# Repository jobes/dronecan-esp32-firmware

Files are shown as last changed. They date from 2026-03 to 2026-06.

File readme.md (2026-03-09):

# InSkyCore DroneCAN Firmware Platform

Low-cost ESP32-based avionics devices for experimental aviation.

This repository is a multi-firmware platform for building DroneCAN nodes and sensors for:

- experimental and ultralight airplanes
- powered hang gliders
- custom cockpit projects

The practical goal is simple: publish important flight and engine data over DroneCAN so the pilot can see everything critical on a tablet in the cockpit.

## Vision

This project focuses on:

- affordable hardware built around ESP32
- reusable DroneCAN software components
- multiple device firmwares in one repository
- fast iteration for real-world flying needs

## Safety Notice

This project is intended for experimental use.

It is not a certified avionics system and must not be treated as the sole source of flight-critical information. Always keep independent, appropriate backup instrumentation.

## Repository Layout

```text
firmware/
	components/                  # Shared ESP-IDF components used by all firmwares
		dronecan_mini/             # DroneCAN communication, node state, params, FW update
		bmp3_sensor_api/           # BMP3/BMP390 sensor integration component
		libcanard/                 # ESP-IDF wrapper/component for libcanard

	firmwares/
		<firmware-name>/           # Individual firmware projects (each has its own README)

	submodules/
		libcanard/                 # Upstream libcanard submodule
		bmp3_sensor_api/           # Upstream BMP3 sensor API submodule
```

## Firmware-Specific Documentation

Each firmware under `firmwares/` has (or should have) its own `readme.md` with:

- hardware details and pinout
- published DroneCAN messages/services
- target MCU and board notes
- exact build/flash commands
- calibration and test notes

## Requirements

- Linux development environment
- ESP-IDF installed (compatible with your project setup)
- USB access to target board
- CAN transceiver and proper wiring for DroneCAN bus

## Quick Start

Clone with submodules:

```bash
git clone --recurse-submodules <REPO_URL>
cd firmware
```

If already cloned, update submodules:

```bash
git submodule update --init --recursive
```

Load ESP-IDF environment:

```bash
. /opt/esp-idf/export.sh
```

Build and flash a selected firmware:

```bash
cd firmwares/<firmware-name>
# Follow target selection and configuration in that firmware's readme.md
idf.py -p /dev/ttyACM1 build flash monitor
```

## How To Add a New Device Firmware

1. Create a new folder under `firmwares/`.
2. Add a standard ESP-IDF project (`CMakeLists.txt`, `main/`, config files).
3. Reuse shared logic from `../../components` (especially `dronecan_mini`).
4. Define per-device settings in `main/project_config.h`.
5. Add sensor/application code in `main/` and publish required DroneCAN topics.
6. Build, flash, and validate on a real CAN bus.

## Design Principles

- Keep common DroneCAN logic in shared components.
- Keep firmware-specific hardware details in each firmware folder.
- Prefer explicit parameters for in-field calibration.
- Optimize for robustness and predictable behavior over features.

## Roadmap Ideas

- additional air-data and environmental sensors
- engine monitoring nodes (EGT/CHT, RPM, pressures)
- electrical system telemetry (voltage/current/battery)
- GPS/attitude helper nodes for glass-cockpit integration
- standardized tablet-friendly data profiles

## Contribution

Contributions and practical flight-test feedback are welcome.

Recommended contribution style:

- keep commits focused and small
- document pinout/protocol assumptions
- include test notes (bench or flight context)

## License

Add the project license information here (for example MIT, BSD, or GPL) once finalized.

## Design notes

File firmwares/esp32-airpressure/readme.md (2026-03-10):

# ESP32 Air Pressure Firmware

Firmware for an ESP32-C3 based DroneCAN air data node using a BMP390 pressure sensor over SPI.

## What This Firmware Does

- Initializes the BMP390 sensor over SPI.
- Joins DroneCAN network over TWAI/CAN.
- Uses DroneCAN dynamic node ID allocation at startup.
- Publishes:
  - `uavcan.equipment.air_data.StaticPressure` (type ID `1028`)
  - `uavcan.equipment.air_data.StaticTemperature` (type ID `1029`)
- Publishes heartbeat (`uavcan.protocol.NodeStatus`) approximately every `950 ms`.
- Exposes runtime parameters for pressure and temperature offsets.

## Hardware Configuration

Defined in `main/project_config.h`.

### CAN (TWAI)

- `CAN_TX_PIN`: `GPIO21`
- `CAN_RX_PIN`: `GPIO20`
- Bitrate: `1 Mbit/s` (`TWAI_TIMING_CONFIG_1MBITS`)

Note: ESP32-C3 requires an external CAN transceiver between MCU TWAI pins and CAN bus.

### BMP390 (SPI)

- `BMP_SCLK`: `GPIO4`
- `BMP_MISO`: `GPIO5`
- `BMP_MOSI`: `GPIO6`
- `BMP_CS`: `GPIO7`
- SPI clock: `1 MHz`

## DroneCAN Node Behavior

- Node starts in `MODE_INITIALIZATION`.
- During startup it requests a dynamic node ID using its unique ID.
- After successful initialization, application switches to `MODE_OPERATIONAL`.
- Main loop period is `100 ms`.
- If sensor read or publish fails, node health is degraded (`WARNING/ERROR/CRITICAL` depending on failure).

## Runtime Parameters

The node registers two float parameters (available over DroneCAN param services):

- `pressure_offset`
  - Range: `-100.0 .. 100.0`
  - Default: `0.0`
  - Applied to published pressure in pascals.
- `temp_offset`
  - Range: `-10.0 .. 10.0`
  - Default: `0.0`
  - Applied to published temperature in degrees Celsius.

Parameters are backed by NVS and can be saved/erased through standard DroneCAN parameter opcodes.

## Build and Flash

From repository root:

```bash
. /opt/esp-idf/export.sh
cd firmwares/esp32-airpressure
# idf.py set-target esp32c3 already set
idf.py -p /dev/ttyACM1 build flash monitor
```

If target is already set, you can skip `set-target`.

## Useful Commands

```bash
# Build only
idf.py build

# Flash only
idf.py -p /dev/ttyACM1 flash

# Monitor only
idf.py -p /dev/ttyACM1 monitor
```

## Project Structure Notes

- Shared components are taken from `../../components`.
- Shared submodules are located in `../../submodules`.
- Partition table is defined in `partitions.csv` (OTA slots + SPIFFS storage).

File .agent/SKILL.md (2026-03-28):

---
name: DroneCAN Firmware Developer
description: Expert in DroneCAN firmware development for ESP32 using ESP-IDF.
---

# DroneCAN ESP32 Firmware Developer Skill

This skill provides expert guidance and automated workflows for developing DroneCAN-based firmware on ESP32 microcontrollers using the ESP-IDF framework.

## Project Structure

- `components/`: Shared ESP-IDF components.
  - `dronecan_mini/`: High-level DroneCAN abstraction (DNA, Parameters, Firmware Update).
  - `libcanard/`: ESP-IDF wrapper for the libcanard library.
- `firmwares/`: Individual firmware projects for different devices.
  - `esp32-airpressure/`: Air pressure sensor node.
  - `esp32-gateway/`: General purpose DroneCAN gateway.
- `submodules/`: External libraries as Git submodules.

## Core Technologies

- **ESP-IDF**: The official development framework for ESP32.
- **DroneCAN**: A lightweight, robust CAN bus protocol for UAVs and robotics.
- **Libcanard**: The underlying DroneCAN implementation in C.

## Multi-Firmware Scalability Strategy

This project is designed to scale to dozens of unique firmware targets. Follow these guidelines to keep the project clean:

### 1. Unified Shared Components
- All logic that can be reused (DroneCAN init, DNA, Heartbeat, Common Messages) must live in `components/dronecan_mini/`.
- Sensor-specific drivers (e.g., BMP380, INA226) should be added as separate components in `components/`

### 2. Standardized Firmware Project Layout
Each firmware in `firmwares/` should follow this template:
- `main/main.c`: The entry point and firmware-specific logic.
- `main/project_config.h`: Key hardware settings (pins, node names, timings).
- `partitions.csv`: Custom partition layout.
- `CMakeLists.txt`: Renames the project and links shared components.
- `readme.md`: Documents HW pinout, specific DroneCAN IDs used, and build notes.

### 3. Naming Conventions
- Firmware folders: `esp32-<functionality>` (e.g., `esp32-egt-sensor`, `esp32-fuel-flow`).
- Node names: `com.inskycore.<firmware-name>` (defined in `project_config.h`).

## Development Workflow

### 1. Build & Flash
Always build and flash from the specific firmware directory under `firmwares/`.

```bash
cd firmwares/<firmware-name>
idf.py build flash monitor
```

### 2. DroneCAN Message Handling
- Shared message definitions are in `components/dronecan_mini/messages/`.
- Receiver logic is in `dronecan_receiver.c`.
- Transmitter logic is typically in `main.c` or a dedicated task.

### 3. Parameters & Configuration
- Per-project configuration is in `main/project_config.h`.
- Custom parameters should be registered in the `dronecan_mini` parameter system.

## Best Practices

1. **Reusability**: Keep protocol-specific and sensor-abstracted logic in `components/`.
2. **Firmware Decoupling**: Keep board-specific pinouts and hardware initialization in the `firmwares/` project's `main/` directory.
3. **Serial Monitoring**: Use `idf.py monitor` for real-time logs.
4. **Git Submodules**: Ensure submodules are updated using `git submodule update --init --recursive`.

## Useful Commands

- `idf.py -p <PORT> build flash monitor`: Complete cycle for a specific firmware.
- `idf.py menuconfig`: Configure firmware settings (WiFi, CAN pins, etc.).
- `idf.py fullclean`: If you encounter weird build issues.

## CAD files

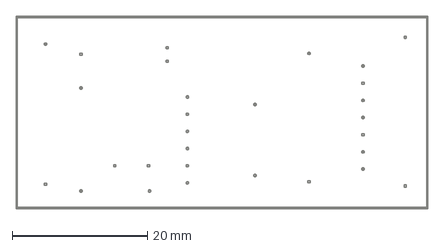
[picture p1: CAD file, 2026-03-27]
firmwares/esp32-airpressure/pcb-supermini-c3-bmp390/pcb-supermini-c3-bmp390-Edge_Cuts.dxf
61.0 x 28.5 mm

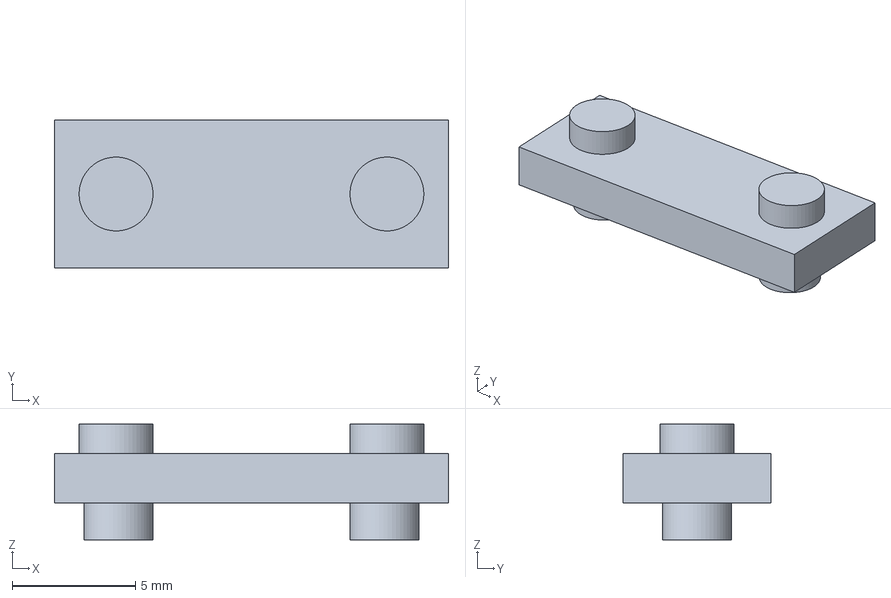
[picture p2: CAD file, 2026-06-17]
firmwares/esp32-airpressure/under-can-holder.FCStd
16.0 x 6.00 x 4.70 mm

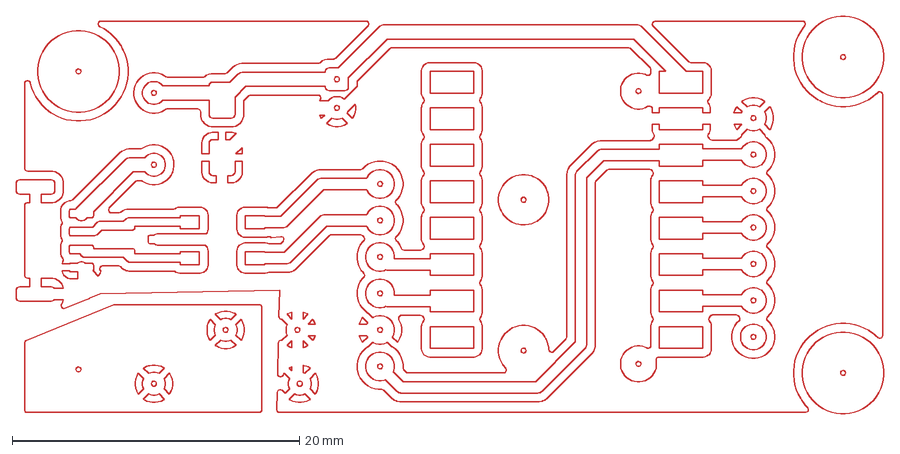
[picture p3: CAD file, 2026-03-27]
firmwares/esp32-airpressure/pcb-supermini-c3-bmp390/pcb-supermini-c3-bmp390-F_Cu.dxf
60.4 x 27.7 mm

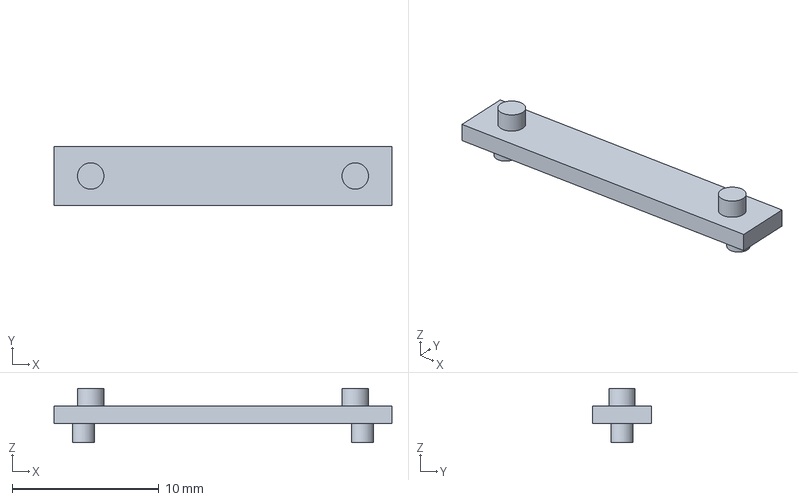
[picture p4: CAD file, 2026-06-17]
firmwares/esp32-airpressure/under-bmp390-holder.FCStd
23.0 x 4.00 x 3.70 mm

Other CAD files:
firmwares/esp32-airpressure/pcb-supermini-c3-bmp390/pcb-supermini-c3-bmp390-F_Mask.dxf

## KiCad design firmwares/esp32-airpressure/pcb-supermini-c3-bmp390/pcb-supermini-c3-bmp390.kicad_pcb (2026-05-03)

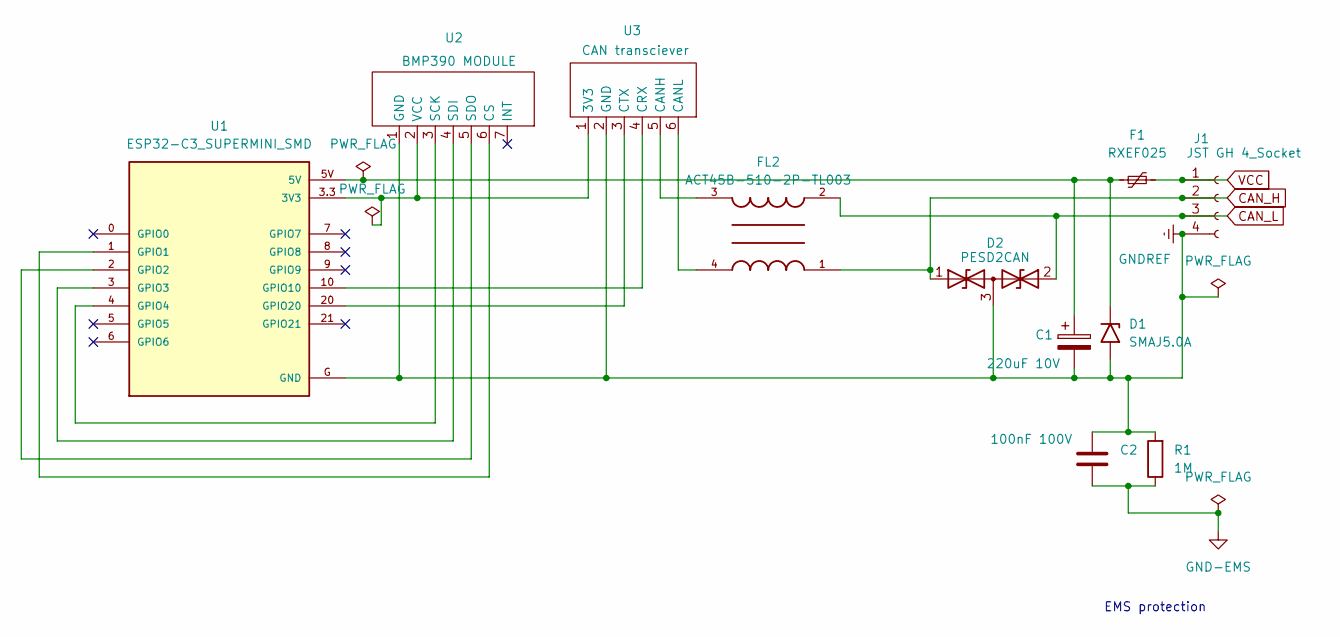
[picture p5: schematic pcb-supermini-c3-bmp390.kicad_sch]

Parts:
C1: 220uF 10V; CP_Radial_D5.0mm_P2.00mm
C2: 100nF 100V; C_Rect_L7.2mm_W3.0mm_P5.00mm_FKS2_FKP2_MKS2_MKP2
D1: SMAJ5.0A; D_SMA
D2: PESD2CAN; SOT-23-3
F1: RXEF025; C_Disc_D4.7mm_W2.5mm_P5.00mm
FL2: ACT45B-510-2P-TL003; FIL_ACT45B-510-2P-TL003; PARTREV 20200405
J1: JST GH 4_Socket; JST_GH_SM04B-GHS-TB_1x04-1MP_P1.25mm_Horizontal
R1: 1M; R_Axial_DIN0207_L6.3mm_D2.5mm_P10.16mm_Horizontal
U1: ESP32-C3_SUPERMINI_SMD; MODULE_ESP32-C3_SUPERMINI
U2: BMP390 MODULE; BMP390_Module
U3: CAN transciever; CAN_Module

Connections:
CAN_H: D2.1 (A1), FL2.1, J1.2
CAN_L: D2.2 (A2), FL2.2, J1.3
GND-EMS: C2.2, R1.1
GNDREF: C1.2, C2.1, D1.2 (A2), D2.3 (common), J1.4, R1.2, U1.G (GND), U2.1 (GND), U3.2 (GND)
unnamed: C1.1, D1.1 (A1), F1.1, U1.5V
unnamed: U1.3.3 (3V3), U2.2 (VCC), U3.1 (3V3)
unnamed: U1.1 (GPIO1), U2.6 (CS)
unnamed: U1.2 (GPIO2), U2.5 (SDO)
unnamed: U1.3 (GPIO3), U2.4 (SDI)
unnamed: U1.4 (GPIO4), U2.3 (SCK)
unnamed: U1.10 (GPIO10), U3.4 (CRX)
unnamed: U1.20 (GPIO20), U3.3 (CTX)
unnamed: FL2.3, U3.5 (CANH)
unnamed: FL2.4, U3.6 (CANL)
VCC: F1.2, J1.1

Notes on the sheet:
EMS protection

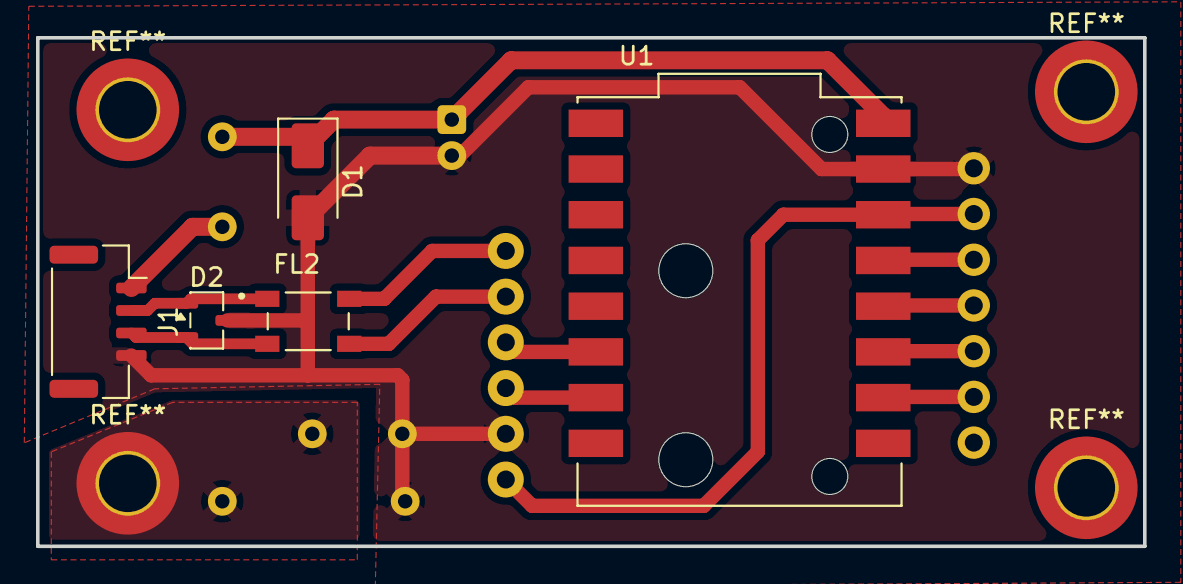
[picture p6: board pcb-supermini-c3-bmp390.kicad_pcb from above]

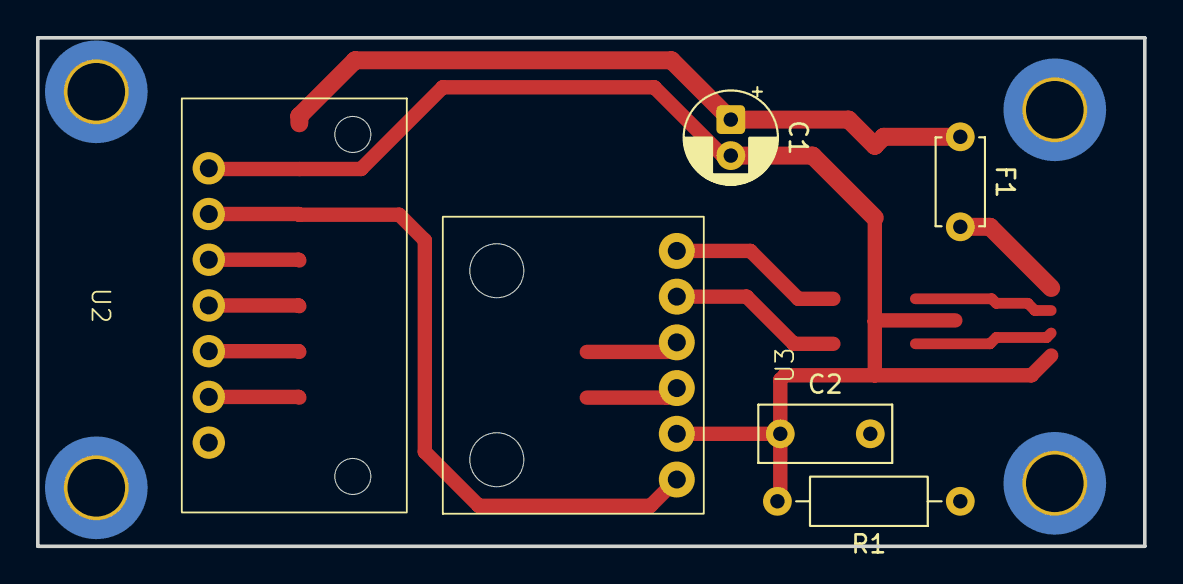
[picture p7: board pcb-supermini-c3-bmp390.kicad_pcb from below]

Board: 2 copper layers, 61.5 x 28.2 mm, 11 parts (6 on the bottom side), 15 nets.

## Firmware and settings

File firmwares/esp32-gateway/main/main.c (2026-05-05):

#include "dronecan_mini/dronecan_tasks.h"
#include "dronecan_dna_server.h"
#include "esp_log.h"

#include "cannelloni_bridge.h"
#include "dronecan_mini/dronecan_node_state.h"
#include "dronecan_mini/dronecan_value_params.h"
#include "dronecan_node_monitor.h"
#include "dronecan_mini/messages/uavcan.equipment.air_data.StaticPressure-1028.h"
#include "dronecan_mini/messages/uavcan.equipment.air_data.StaticTemperature-1029.h"
#include "wifi_manager.h"

static const char *TAG = "APP";

static void main_task(void *arg)
{
  ESP_LOGI(TAG, "Application task started");

  if (*get_node_mode() == MODE_INITIALIZATION)
  {
    set_node_mode(MODE_OPERATIONAL);
  }

  while (1)
  {
    if (*get_node_mode() != MODE_OPERATIONAL)
    {
      ESP_LOGW(
          TAG,
          "Node is not in operational mode, skipping sensor read and publish");
      vTaskDelay(pdMS_TO_TICKS(1000));
      continue;
    }
    dronecan_node_monitor_tick();
    vTaskDelay(pdMS_TO_TICKS(100));
  }
}

void app_main(void)
{
  union DeviceParameter device_parameters[] = {
      {.String = {DEVICE_PARAM_TYPE_STRING, "HOSTNAME", "airplane_gateway"}},
      {.String = {DEVICE_PARAM_TYPE_STRING, "AP_SSID", "airplane_gateway"}},
      {.String = {DEVICE_PARAM_TYPE_STRING, "AP_PASSWORD", "airplane123456"}},
      {.String = {DEVICE_PARAM_TYPE_STRING, "STA_SSID", ""}},
      {.String = {DEVICE_PARAM_TYPE_STRING, "STA_PASSWORD", ""}},
  };

  set_device_parameters(device_parameters, ARRAY_SIZE(device_parameters));
  wifi_init_manager();
  cannelloni_bridge_init();
  dronecan_set_rx_frame_listener(cannelloni_bridge_push_frame);
  dronecan_set_tx_frame_listener(cannelloni_bridge_push_frame);
  init_tasks(main_task, 1, 1); // Core 1 for CAN/DroneCAN tasks
  dronecan_dna_server_init();
}

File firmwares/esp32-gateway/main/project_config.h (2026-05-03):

#ifndef PROJECT_CONFIG_H
#define PROJECT_CONFIG_H

// stringify helper
#define _STR(x) #x
#define STR(x) _STR(x)

// node info
#define DEVICE_NAME "com.inskycore.dronecan_node.gateway"
#define DEVICE_NAME_LEN (sizeof(DEVICE_NAME) - 1)
#define DEVICE_INSTANCE_NAME "avionics-dronecan"
#define DEVICE_INSTANCE_NAME_LEN (sizeof(DEVICE_INSTANCE_NAME) - 1)

#define MINOR_SW_VERSION 1
#define MAJOR_SW_VERSION 0

#define MINOR_HW_VERSION 1
#define MAJOR_HW_VERSION 0

// dronecan
#define CAN_TX_PIN GPIO_NUM_17
#define CAN_RX_PIN GPIO_NUM_18
#define CAN_SPEED TWAI_TIMING_CONFIG_1MBITS
#define CAN_CONFIG TWAI_FILTER_CONFIG_ACCEPT_ALL
#define CAN_MODE TWAI_MODE_NORMAL
#define CAN_READ_TIMEOUT_MS 10
#define DRONECAN_MEM_POOL_SIZE 4096
#define DRONECAN_HEARTBEAT_INTERVAL_MS 950 // 1 second interval with some margin

// cannelloni
#define CANNELLONI_UDP_PORT 20000
#define CANNELLONI_MAX_PEERS 5
#define CANNELLONI_PEER_TIMEOUT_MS 3000
#define CANNELLONI_TX_INTERVAL_MS 10

#endif

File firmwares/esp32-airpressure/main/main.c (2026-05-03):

#include "dronecan_mini/dronecan_tasks.h"
#include "esp_log.h"

#include "bmp390.h"
#include "dronecan_mini/dronecan_value_params.h"
#include "dronecan_mini/dronecan_node_state.h"
#include "dronecan_mini/messages/uavcan.equipment.air_data.StaticPressure-1028.h"
#include "dronecan_mini/messages/uavcan.equipment.air_data.StaticTemperature-1029.h"

static const char *TAG = "APP";

static void main_task(void *arg)
{
    ESP_LOGI(TAG, "Application task started");
    if (bmp390_spi_init() != ESP_OK)
    {
        set_node_health(HEALTH_CRITICAL);
        vTaskDelete(NULL);
    }

    if (*get_node_mode() == MODE_INITIALIZATION)
    {
        set_node_mode(MODE_OPERATIONAL);
    }

    while (1)
    {
        if (*get_node_mode() != MODE_OPERATIONAL)
        {
            ESP_LOGW(TAG, "Node is not in operational mode, skipping sensor read and publish");
            vTaskDelay(pdMS_TO_TICKS(1000));
            continue;
        }
        struct bmp3_data data;
        if (bmp390_get_data(&data) == BMP3_OK)
        {
            float pressure_variance_pa2 = 100.0f; // 0.8 meters variance
            float temperature_variance_c2 = 1.0f; // 1 degrees Celsius variance

            bool pressure_publish_ok = publish_1028_staticPressure((float)data.pressure + get_device_parameters()[0].Float.value, pressure_variance_pa2);
            bool temperature_publish_ok = publish_1029_staticTemperatureCelsius((float)data.temperature + get_device_parameters()[1].Float.value, temperature_variance_c2);

            if (pressure_publish_ok && temperature_publish_ok)
            {
                set_node_health(HEALTH_OK);
            }
            else
            {
                if (temperature_publish_ok)
                {
                    ESP_LOGE(TAG, "Failed to publish static pressure");
                    set_node_health(HEALTH_CRITICAL);
                }
                else
                {
                    ESP_LOGE(TAG, "Failed to publish temperature");
                    set_node_health(HEALTH_ERROR);
                }
            }
        }
        else
        {
            ESP_LOGE(TAG, "Failed to read data from BMP390 sensor");
            set_node_health(HEALTH_CRITICAL);
        }
        vTaskDelay(pdMS_TO_TICKS(100));
    }
}

void param_changed(uint16_t index)
{
    ESP_LOGI(TAG, "Parameter index %d changed", index);
}

void app_main(void)
{
    union DeviceParameter device_parameters[] = {
        {.Float = {DEVICE_PARAM_TYPE_FLOAT, "pressure_offset", -100.0, 100.0, 0.0}},
        {.Float = {DEVICE_PARAM_TYPE_FLOAT, "temp_offset", -10.0, 10.0, 0.0}},
    };

    set_param_changed_callback(param_changed);
    set_device_parameters(device_parameters, ARRAY_SIZE(device_parameters));
    init_tasks(main_task, 0, tskNO_AFFINITY);
}

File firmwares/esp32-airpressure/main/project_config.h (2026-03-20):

#ifndef PROJECT_CONFIG_H
#define PROJECT_CONFIG_H

// node info
#define DEVICE_NAME "com.inskycore.dronecan_node.pressure_sensor"
#define DEVICE_NAME_LEN (sizeof(DEVICE_NAME) - 1)
#define MINOR_SW_VERSION 1
#define MAJOR_SW_VERSION 0

#define MINOR_HW_VERSION 1
#define MAJOR_HW_VERSION 0

// dronecan
#define CAN_TX_PIN GPIO_NUM_20
#define CAN_RX_PIN GPIO_NUM_10
#define CAN_SPEED TWAI_TIMING_CONFIG_1MBITS
#define CAN_CONFIG TWAI_FILTER_CONFIG_ACCEPT_ALL
#define CAN_MODE TWAI_MODE_NORMAL
#define CAN_READ_TIMEOUT_MS 10
#define DRONECAN_MEM_POOL_SIZE 4096
#define DRONECAN_HEARTBEAT_INTERVAL_MS 950 // 1 second interval with some margin

// BMP390
#define BMP_CS GPIO_NUM_1
#define BMP_MISO GPIO_NUM_2
#define BMP_MOSI GPIO_NUM_3
#define BMP_SCLK GPIO_NUM_4
#define SPI_SPEED_HZ 1000000

#endif

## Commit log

2026-02-20 add BMP390 sensor integration and update project configuration
2026-02-20 add static pressure publishing to DroneCAN and update broadcast function
2026-02-20 move pressure message to own file
2026-02-20 add StaticTemperature message handling and integrate temperature publishing
2026-02-22 device parameters load from nvm, but can be changed via can
2026-02-22 Implement parameter change notification and refactor device parameter handling
2026-02-25 firmware update over CAN
    [partitions.csv]
2026-03-09 make library style so we can have more firmware
    [partitions.csv]
2026-03-10 update readme to clarify that target for esp32c3 is already set
2026-03-19 Add symbol library and components for BMP390 and CAN transceiver
    - Created a new symbol library file for the ESP32-C3 Supermini project.
    - Added symbols for BMP390 module and CAN transceiver with their respective properties and pin configurations.
    - Included necessary metadata for the symbol library to ensure compatibility with KiCad.
    [pcb-supermini-c3-bmp390.kicad_pcb, pcb-supermini-c3-bmp390.kicad_sch]
2026-03-20 refactor: update PCB to be on 2 layers
    [pcb-supermini-c3-bmp390.kicad_pcb, pcb-supermini-c3-bmp390.kicad_sch]
2026-03-20 chore: Update libcanard core, drivers, tests, examples, C++ wrappers, and build configurations.
2026-03-27 feat: Add new ESP32 air pressure sensor PCB design
    [pcb-supermini-c3-bmp390-Edge_Cuts.dxf, pcb-supermini-c3-bmp390-F_Cu.dxf, pcb-supermini-c3-bmp390-F_Mask.dxf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]
2026-03-28 esp32-gateway empty basic empty firmware
    [partitions.csv]
2026-03-28 feat: Implement Wi-Fi manager and device parameter retrieval functions
    [partitions.csv]
2026-03-28 feat: Add HTTP server and mDNS service for device discovery
2026-03-28 feat: Advertise Cannelloni service for CAN bus tunneling in mDNS
2026-05-03 Refactor ESP32 Gateway Firmware
    - Updated main.c to include cannelloni_bridge and improved task management.
    - Modified project_config.h to change CAN TX/RX pins and added Cannelloni configuration parameters.
    - Added new HTML files for station mode configuration, device status, and system settings.
    - Created a template HTML file for consistent UI styling across the web interface.
    - Enhanced wifi_manager.c to improve WiFi connection handling and added support for Cannelloni services.
    - Updated sdkconfig to set the CPU frequency to 240 MHz for better performance.
    [pcb-supermini-c3-bmp390.kicad_pcb]
2026-05-03 fix: streamline CAN frame transmission and update ESP-IDF version to 6.0.1
2026-05-04 fix: improve error handling in CAN frame processing and update Cannelloni frame size definitions
2026-05-05 Add DroneCAN Node Monitoring and Update Web Interface
    - Introduced dronecan_node_monitor.h for managing DroneCAN node information.
    - Updated http_server.c to handle new routes for nodes and status APIs.
    - Implemented new HTML pages for displaying node information and device status.
    - Added JavaScript for dynamic updates of node data and device uptime.
    - Created CSS styles for improved UI presentation of node information.
    - Removed outdated HTML files related to STA and system settings.
    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
2026-06-17 Enhance PCB configuration and add new holders
    - Updated PCB project settings in `pcb-supermini-c3-bmp390.kicad_pro` to improve zone parameters and error handling.
    - Introduced new annotation settings for schematic management.
    - Added `under-bmp390-holder.FCStd` and `under-can-holder.FCStd` files for component support.
    [under-bmp390-holder.FCStd, under-can-holder.FCStd]
